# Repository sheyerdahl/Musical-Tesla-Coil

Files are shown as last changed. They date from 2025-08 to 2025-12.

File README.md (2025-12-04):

Welcome
======
A DRSSTC (Dual Resonant Solid State Tesla Coil) project that uses the ESP32-S3-WROOM-1 module as the microcontroller and wireless communication. 

My primary circuit uses the SKM100GB125DN IGBT

Notes
-------
The first revision (REV 1.0) being my first PCB, had quite a few issues and oversights. REV 2.0 will fix these issues, although it will be untested.
Some of the issues that were fixed:

Lack of OCD Comparator
Lack of peak detector circuit for measuring current
Lack of ZCD Comparator
USB-C footprint being incorrect
Slow diodes being used in the GDT circuit
Lack of mounting holes
Using built-in ADC of ESP32, an external one would have significantly more ENOB. (Effective Number Of Bits)
No Reverse polarity protection, no over current protection.

Credits
-------
Most design decisions were made because of Mads Barnkob and his awesome [website](https://kaizerpowerelectronics.dk/tesla-coils/drsstc-design-guide/) and [Youtube videos](https://www.youtube.com/@KaizerPowerElectronicsDk).

Thanks to those who worked on the [UD3 Board](https://github.com/Netzpfuscher/UD3), some of their hardware design was copied to this one.

[JAVATC3D](https://www.classictesla.com/java/javatc3d/javatc3d.html)

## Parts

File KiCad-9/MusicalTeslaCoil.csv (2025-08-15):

Id | Designator | Footprint | Quantity | Designation | Supplier and ref
1 | C1,C4,C37,C19,C24,C28,C36,C29 | C_0805_2012Metric_Pad1.18x1.45mm_HandSolder | 8 | 0.1uF
2 | J14 | PinHeader_2x03_P2.54mm_Vertical | 1 | Conn_02x03_Odd_Even
3 | C21,C7,C13,C33,C32,C26 | C_0805_2012Metric_Pad1.18x1.45mm_HandSolder | 6 | 1nF
4 | R10,R12 | R_0805_2012Metric_Pad1.20x1.40mm_HandSolder | 2 | 3k 1%
5 | J3 | Molex_KK-254_AE-6410-02A_1x02_P2.54mm_Vertical | 1 | VBUS
6 | C42,C2,C38,C39,C23,C35 | C_0805_2012Metric_Pad1.18x1.45mm_HandSolder | 6 | 1uF
7 | R13,R14,R29,R26,R21,R24,R30,R17 | R_0805_2012Metric_Pad1.20x1.40mm_HandSolder | 8 | 1k
8 | U3 | DCK5_TEX | 1 | LMV321
9 | C6 | C_0805_2012Metric_Pad1.18x1.45mm_HandSolder | 1 | 10nF
10 | R6,R2,R1,R27,R28,R22,R23 | R_0805_2012Metric_Pad1.20x1.40mm_HandSolder | 7 | 10k
11 | R15,R16 | R_0805_2012Metric_Pad1.20x1.40mm_HandSolder | 2 | 50
12 | J4 | Molex_KK-254_AE-6410-02A_1x02_P2.54mm_Vertical | 1 | Primary Relay
13 | Q1,Q2 | QNMOS1G2S3D_TO-236AB_SOT23_NEX | 2 | PMV20ENR
14 | CR1,CR11,CR10,CR9,CR8,CR2 | CR_SOD-123FL_SME | 6 | 1N4007FL
15 | J9 | Molex_KK-254_AE-6410-02A_1x02_P2.54mm_Vertical | 1 | NTC Thermistor 1
16 | U2 | SOT-23-6W_PE-SOT23-6W-0512_NMD | 1 | R1240N001B-TR-FE
17 | L1 | IND_7045_TDK | 1 | SLF7045T-4R7M2R0-PF
18 | CR13 | M-FLAT_TOS | 1 | CMS06TE12L_Q_M
19 | CR12 | DIODE_MSP3V3 | 1 | MSS1P4-M3/89A
20 | CR6,CR5,CR4,CR3 | DO-214AA_VIS | 4 | ES2B-E3/52T
21 | SW1 | SO4_222A-M-V-B_CTS | 1 | USB Boot
22 | U1 | ESP32-S3-WROOM-1 | 1 | ESP32-S3-WROOM-1
23 | SW2 | SO4_222A-M-V-B_CTS | 1 | Reset
24 | C3 | C_0805_2012Metric_Pad1.18x1.45mm_HandSolder | 1 | 22uF
25 | J1 | USB_C-UJ20-C-H-C-MSMT-TR | 1 | USB_C-UJ20-C-H-C-MSMT-TR
26 | R35 | R_0805_2012Metric_Pad1.20x1.40mm_HandSolder | 1 | 6.3k 1%
27 | C41 | C_0805_2012Metric_Pad1.18x1.45mm_HandSolder | 1 | 470pF
28 | R34 | R_0805_2012Metric_Pad1.20x1.40mm_HandSolder | 1 | 51
29 | U10 | SOT95P285X140-5N | 1 | AP2112K-3.3TRG1
30 | C40,C5 | C_0805_2012Metric_Pad1.18x1.45mm_HandSolder | 2 | 10uF
31 | R36 | R_0805_2012Metric_Pad1.20x1.40mm_HandSolder | 1 | 1.2k 1%
32 | J2 | Molex_KK-254_AE-6410-02A_1x02_P2.54mm_Vertical | 1 | Power in
33 | U5,U7 | SOIC127P599X175-8N | 2 | UCC27423DR
34 | C16,C15,C14,C17 | C_0805_2012Metric_Pad1.18x1.45mm_HandSolder | 4 | 150pF
35 | R39,R38,R37,R20 | R_0805_2012Metric_Pad1.20x1.40mm_HandSolder | 4 | 3.3 0.5W
36 | J13 | PinHeader_1x06_P2.54mm_Vertical | 1 | Conn_01x06_Pin
37 | J12 | PinHeader_1x05_P2.54mm_Vertical | 1 | Conn_01x05_Pin
38 | J11 | PinHeader_1x10_P2.54mm_Vertical | 1 | Conn_01x10_Pin
39 | C31,C30,C27,C18,C20,C25 | C_0805_2012Metric_Pad1.18x1.45mm_HandSolder | 6 | 4.7uF
40 | FL1 | FL4_WCM7060_TTA | 1 | WCM 7060FASF-701-LM
41 | R3,R11 | R_0805_2012Metric_Pad1.20x1.40mm_HandSolder | 2 | 5.1k
42 | J5 | Molex_KK-254_AE-6410-02A_1x02_P2.54mm_Vertical | 1 | Soft Start Bypass Relay
43 | CR7 | CR_V3-E3&slash_52_VIS | 1 | SMBJ3V3-E3/52
44 | J8 | Molex_KK-254_AE-6410-02A_1x02_P2.54mm_Vertical | 1 | GDT2
45 | R33,R32 | R_0805_2012Metric_Pad1.20x1.40mm_HandSolder | 2 | 1k 1%
46 | R25,R31 | R_0805_2012Metric_Pad1.20x1.40mm_HandSolder | 2 | 15
47 | R19,R18 | R_0805_2012Metric_Pad1.20x1.40mm_HandSolder | 2 | 100
48 | J7 | Molex_KK-254_AE-6410-02A_1x02_P2.54mm_Vertical | 1 | GDT1
49 | U4,U6,U9,U8 | TO252-4_DMC4029SK4-13_DIO | 4 | DMC4029SK4-13
50 | J6 | Molex_KK-254_AE-6410-02A_1x02_P2.54mm_Vertical | 1 | Current Transformer
51 | C22,C34 | C_0805_2012Metric_Pad1.18x1.45mm_HandSolder | 2 | 2.2uF
52 | J10 | Molex_KK-254_AE-6410-02A_1x02_P2.54mm_Vertical | 1 | NTC Thermistor 2
53 | R7 | R_0805_2012Metric_Pad1.20x1.40mm_HandSolder | 1 | 100k

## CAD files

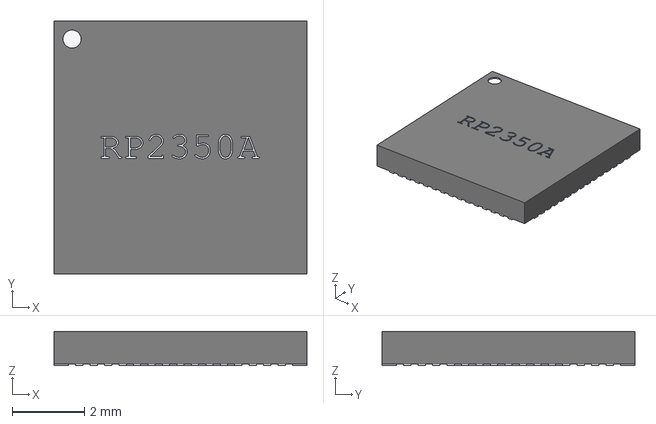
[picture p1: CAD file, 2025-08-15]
KiCad-9/MusicalTeslaCoil.step
7.00 x 7.00 x 0.95 mm

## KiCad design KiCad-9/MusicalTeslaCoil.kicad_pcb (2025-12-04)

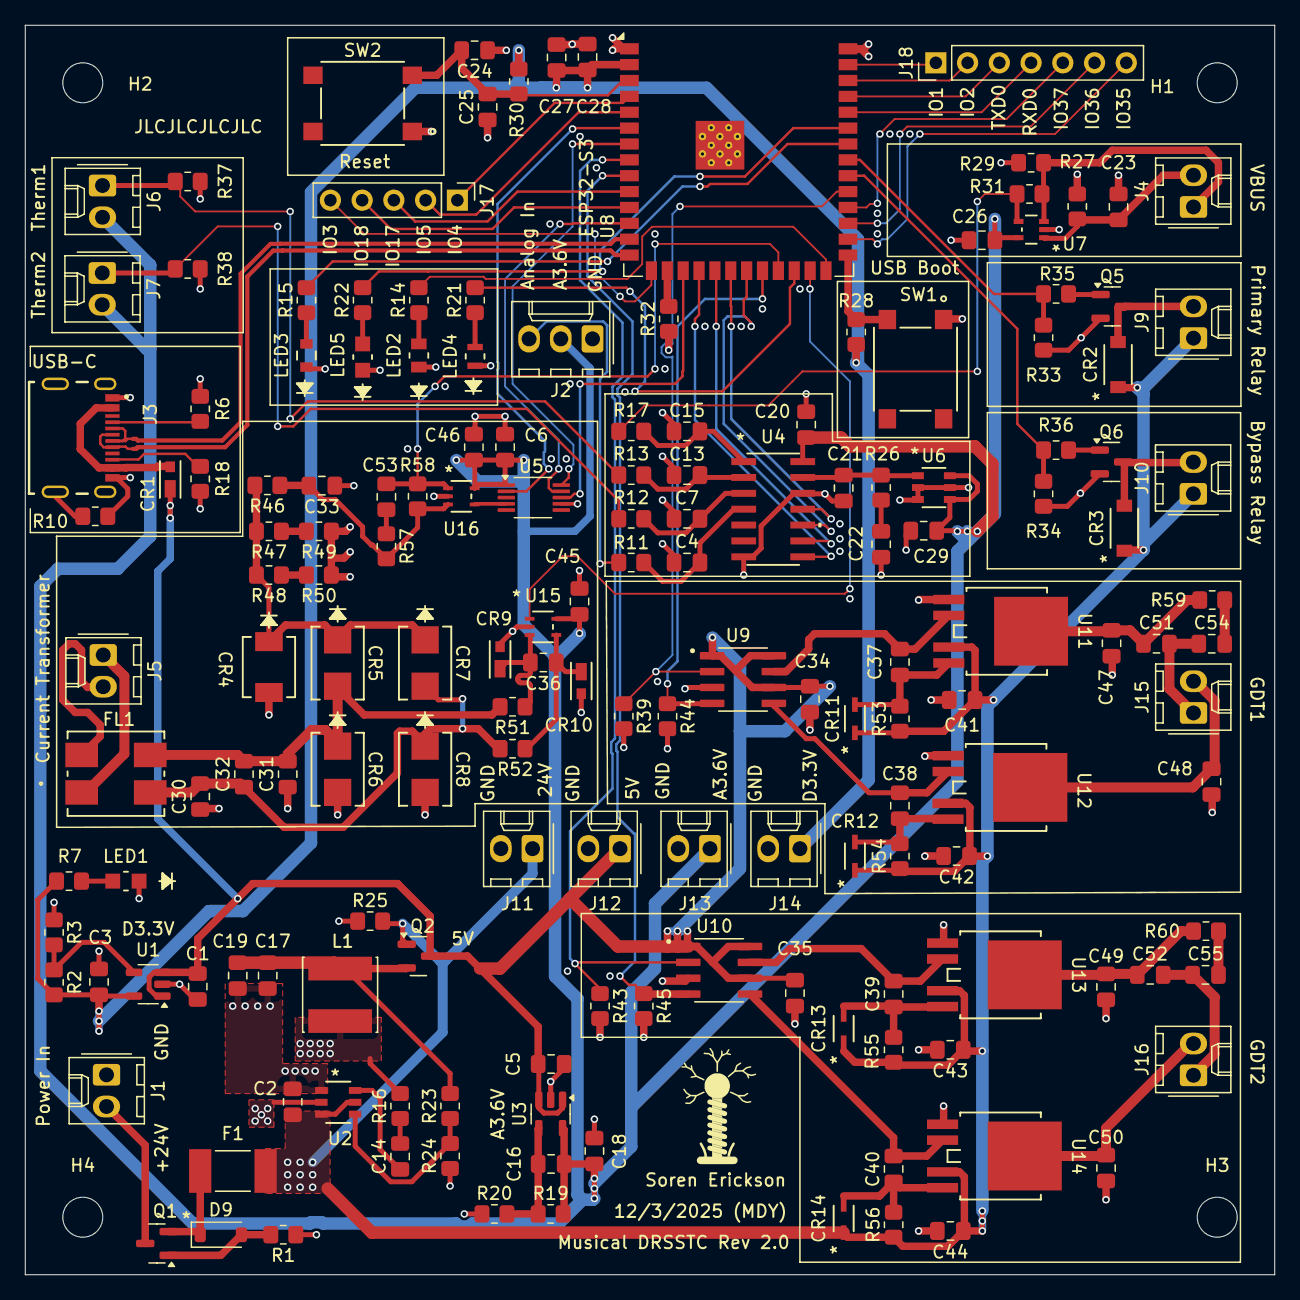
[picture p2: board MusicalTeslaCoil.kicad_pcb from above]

Board: 4 copper layers, 100.0 x 100.0 mm, 169 parts (0 on the bottom side), 105 nets.

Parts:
C1, C3, C5, C18, C20, C22, C29, C51, C52: 2.2uF; C_0805_2012Metric_Pad1.18x1.45mm_HandSolder
C2, C17, C19, C27, C28: 10uF; C_0805_2012Metric_Pad1.18x1.45mm_HandSolder
C4, C7, C13, C15, C16, C23: 10nF; C_0805_2012Metric_Pad1.18x1.45mm_HandSolder
C6, C25, C45, C46, C54, C55: 1uF; C_0805_2012Metric_Pad1.18x1.45mm_HandSolder
C14, C24, C26, C37, C38, C39, C40: 0.1uF; C_0805_2012Metric_Pad1.18x1.45mm_HandSolder
C21, C32, C47, C48, C49, C50: 1nF; C_0805_2012Metric_Pad1.18x1.45mm_HandSolder
C30, C31, C33, C36: 150pF; C_0805_2012Metric_Pad1.18x1.45mm_HandSolder
C34, C35, C41, C42, C43, C44: 4.7uF; C_0805_2012Metric_Pad1.18x1.45mm_HandSolder
C53: 470pF; C_0805_2012Metric_Pad1.18x1.45mm_HandSolder
CR1, CR9, CR10: MSS1P4-M3/89A; DIODE_MSP3V3
CR2, CR3: 1N4007FL; CR_SOD-123FL_SME
CR4: SMBJ3V3-E3/52; CR_V3-E3&slash_52_VIS
CR5, CR6, CR7, CR8: ES2B-E3/52T; DO-214AA_VIS
CR11, CR12, CR13, CR14: 1N4148WS-7-F; CR_SOD323_MCC
D9: BZT52C15-7-F; D_SOD-123
F1: 0ZCG0050AF2C; FUSER_0ZCG0050AF2C
FL1: WCM 7060FASF-701-LM; FL4_WCM7060_TTA
H1, H2, H3, H4: MountingHole; MountingHole_3.2mm_M3
J1: Power in; Molex_KK-254_AE-6410-02A_1x02_P2.54mm_Vertical
J2: Conn_01x03; Molex_KK-254_AE-6410-03A_1x03_P2.54mm_Vertical
J3: USB4215-03-A; USB4215_03_A
J4: VBUS; Molex_KK-254_AE-6410-02A_1x02_P2.54mm_Vertical
J5: Current Transformer; Molex_KK-254_AE-6410-02A_1x02_P2.54mm_Vertical
J6: NTC Thermistor 1; Molex_KK-254_AE-6410-02A_1x02_P2.54mm_Vertical
J7: NTC Thermistor 2; Molex_KK-254_AE-6410-02A_1x02_P2.54mm_Vertical
J9: Primary Relay; Molex_KK-254_AE-6410-02A_1x02_P2.54mm_Vertical
J10: Soft Start Bypass Relay; Molex_KK-254_AE-6410-02A_1x02_P2.54mm_Vertical
J11, J12, J13, J14: Conn_01x02; Molex_KK-254_AE-6410-02A_1x02_P2.54mm_Vertical
J15: GDT1; Molex_KK-254_AE-6410-02A_1x02_P2.54mm_Vertical
J16: GDT2; Molex_KK-254_AE-6410-02A_1x02_P2.54mm_Vertical
J17: Conn_01x05; PinHeader_1x05_P2.54mm_Vertical
J18: Conn_01x07; PinHeader_1x07_P2.54mm_Vertical
L1: VLS6045EX-150M; VLS6045EX_150M
LED1, LED5: LTST-C170GKT; LED_LTST-C170GKT_LTO
LED2: LTST-C170KFKT; LED_LTST-C170KFKT_LTO
LED3: LTST-C171KRKT; LED_LTST-C171_LTO
LED4: LTST-C170KSKT; LED_LTST-C170KSKT_LTO
Q1: GSF3407; SOT-23
Q2: SSF7912; SOT-23
Q5, Q6: 2N7002K; SOT-23
R1, R6, R18: 5.1k; R_0805_2012Metric_Pad1.20x1.40mm_HandSolder
R2, R19, R24, R29, R31: 3k; R_0805_2012Metric_Pad1.20x1.40mm_HandSolder
R3: 15k; R_0805_2012Metric_Pad1.20x1.40mm_HandSolder
R7, R14, R15, R21, R22, R57: 150; R_0805_2012Metric_Pad1.20x1.40mm_HandSolder
R10: 100k; R_0805_2012Metric_Pad1.20x1.40mm_HandSolder
R11, R12, R13, R17, R37, R38, R46, R51, R52, R53, R54, R55, R56: 1k; R_0805_2012Metric_Pad1.20x1.40mm_HandSolder
R16: 0; R_0805_2012Metric_Pad1.20x1.40mm_HandSolder
R20: 16.5k; R_0805_2012Metric_Pad1.20x1.40mm_HandSolder
R23: 22k; R_0805_2012Metric_Pad1.20x1.40mm_HandSolder
R25, R28, R30, R32, R33, R34, R39, R43, R44, R45: 10k; R_0805_2012Metric_Pad1.20x1.40mm_HandSolder
R26, R35, R36: 51; R_0805_2012Metric_Pad1.20x1.40mm_HandSolder
R27: 1.5k; R_0805_2012Metric_Pad1.20x1.40mm_HandSolder
R47, R48, R49, R50: 3.3 0.5W; R_0805_2012Metric_Pad1.20x1.40mm_HandSolder
R58: 200k; R_0805_2012Metric_Pad1.20x1.40mm_HandSolder
R59, R60: 15; R_0805_2012Metric_Pad1.20x1.40mm_HandSolder
SW1: USB Boot; SO4_222A-M-V-B_CTS
SW2: Reset; SO4_222A-M-V-B_CTS
U1, U3: TLV75801PDBV; SOT-23-5
U2: TPP362082-T6TR; TSOT23-6-A_TPK
U4: MCP3204T-CI/SL; SOIC14-N_MC_MCH
U5: MCP48FVB11
U6: MCP1501T-33E/CHY; SOT-23-6_CHY_MCH
U7: MCP6006UT-E/LT; SC70-5_LT_MCH
U8: ESP32-S3-WROOM-1
U9, U10: UCC27423DR; SOIC127P599X175-8N
U11, U12, U13, U14: DMC4029SK4-13; TO252-4_DMC4029SK4-13_DIO
U15, U16: NCS2250SQ2T2G; SC70-5_2P2X1P35_ONS

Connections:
5V: C1.2, C5.2, C34.2, C35.2, CR1.1, J12.1, Q2.3 (D), U1.1 (IN), U1.3 (EN), U3.1 (IN), U3.3 (EN), U9.1 (ENBA), U9.6 (VDD), U9.8 (ENBB), U10.1 (ENBA), U10.6 (VDD), U10.8 (ENBB)
24V: C2.1, C41.1, C42.1, C43.1, C44.1, CR2.1, CR3.1, CR11.1, CR12.1, CR13.1, CR14.1, F1.1, J9.1, J10.1, J11.1, Q2.1 (G), R25.2, R53.1, R54.1, R55.1, R56.1, U2.3 (VIN), U2.5 (EN), U11.3 (P-Chan_S), U12.3 (P-Chan_S), U13.3 (P-Chan_S), U14.3 (P-Chan_S)
A3.6V: C6.2, C16.2, C18.2, C20.2, C26.2, C29.2, C45.2, C46.2, J2.2, J6.2, J7.2, J13.1, R19.2, U3.5 (OUT), U4.14 (VDD), U5.1 (VDD), U6.4 (*SHDN), U6.6 (VDD), U7.5 (V+), U15.5 (V+), U16.5 (V+)
ADC_CLK: U4.11 (CLK), U8.20 (IO12)
ADC_CS: U4.8 (*CS/SHDN), U8.18 (IO10)
ADC_DIN: U4.9 (DIN), U8.19 (IO11)
ADC_DOUT: U4.10 (DOUT), U8.21 (IO13)
BypassRelay: R34.1, R36.2, U8.32 (IO39)
CTOut: C33.2, R46.1, R57.2, R58.2, U16.3 (+)
D3.3V: C3.2, C27.2, C28.1, J14.1, R2.2, R7.2, R28.1, R30.1, U1.5 (OUT), U8.2 (3V3)
DACVOut: U5.4 (VOut), U16.4 (-)
DAC_CLK: U5.9 (SCK), U8.12 (IO8)
DAC_CS: U5.2 (*CS), U8.6 (IO6)
DAC_DIN: U5.10 (SDI), U8.7 (IO7)
DAC_DOUT: U5.8 (SDO), U8.17 (IO9)
GD1-A: R39.1, U8.31 (IO38), U9.2 (INA)
GD1-B: R44.1, U8.22 (IO14), U9.4 (INB)
GD2-A: R43.1, U8.8 (IO15), U10.2 (INA)
GD2-B: R45.1, U8.9 (IO16), U10.4 (INB)
GND: C1.1, C2.2, C3.1, C4.1, C5.1, C6.1, C7.1, C13.1, C15.1, C17.2, C18.1, C19.2, C20.1, C21.1, C22.1, C23.1, C24.1, C25.1, C26.1, C27.1, C28.2, C29.1, C30.1, C31.1, C33.1, C34.1, C35.1, C41.2, C42.2, C43.2, C44.2, C45.1, C46.1, C47.2, C48.2, C49.2, C50.2, CR4.2, CR6.2, CR8.2, CR9.2, CR10.2, J1.1, J2.1, J3.A1_B12 (GND_A), J3.B1_A12 (GND_B), J11.2, J12.2, J13.2, J14.2, LED1.1, LED2.1, LED3.1, LED4.1, LED5.1, Q5.2 (S), Q6.2 (S), R1.1, R3.1, R6.1, R10.2, R18.1, R20.1, R24.1, R25.1, R27.1, R29.1, R32.1, R33.2, R34.2, R37.2, R38.2, R39.2, R43.2, R44.2, R45.2, R49.1, R50.1, SW1.1 (A), SW2.1 (A), U1.2 (GND), U2.1 (GND), U3.2 (GND), U4.7 (DGND), U4.12 (AGND), U5.7 (GND), U6.2 (GND), U6.3 (GND), U6.5 (GND), U7.2 (V-), U8.1 (GND), U8.40 (GND), U8.41 (GND), U9.3 (GND), U10.3 (GND), U11.1 (N-Chan_S), U12.1 (N-Chan_S), U13.1 (N-Chan_S), U14.1 (N-Chan_S), U15.2 (V-), U16.2 (V-)
IO1: J18.1, U8.39 (IO1)
IO2: J18.2, U8.38 (IO2)
IO3: J17.5, U8.15 (IO3)
IO4: J17.1, U8.4 (IO4)
IO5: J17.2, U8.5 (IO5)
IO17: J17.3, U8.10 (IO17)
IO18: J17.4, U8.11 (IO18)
IO35: J18.7, U8.28 (IO35)
IO36: J18.6, U8.29 (IO36)
IO37: J18.5, U8.30 (IO37)
LED1: R15.2, U8.34 (IO41)
LED2: R22.2, U8.35 (IO42)
LED3: R14.2, U8.26 (IO45)
LED4: R21.2, U8.24 (IO47)
unnamed: C14.2, R16.1
unnamed: C22.2, R26.1
unnamed: C30.2, C32.1, CR7.2, CR8.1, FL1.3, R52.2
unnamed: C31.2, C32.2, CR5.2, CR6.1, FL1.4, R51.2
unnamed: C53.2, R57.1
unnamed: C54.2, R59.2
unnamed: C55.2, R60.2
unnamed: CR4.1, CR5.1, CR7.1, R46.2, R47.2, R48.2
unnamed: D9.2 (A), Q1.1 (G), R1.2
unnamed: D9.1 (K), F1.2, Q1.2 (S)
unnamed: J1.2, Q1.3 (D)
unnamed: J2.3, R11.2
unnamed: J3.A5 (CC1), R6.2
unnamed: J3.B5 (CC2), R18.2
unnamed: J3.SH4 (SHIELD__3), R10.1
unnamed: CR1.2, J3.A4_B9 (VBUS_A), J3.B4_A9 (VBUS_B)
unnamed: J4.1, R29.2, R31.2, U7.3 (-)
unnamed: C23.2, J4.2, R27.2, U7.1 (+)
unnamed: FL1.2, J5.1
unnamed: FL1.1, J5.2
unnamed: CR2.2, J9.2, Q5.3 (D)
unnamed: CR3.2, J10.2, Q6.3 (D)
unnamed: C51.1, C54.1, J15.1
unnamed: C48.1, J15.2, U12.5 (Drain)
unnamed: C52.1, C55.1, J16.1
unnamed: C50.1, J16.2, U14.5 (Drain)
unnamed: LED1.2, R7.1
unnamed: LED2.2, R14.1
unnamed: LED3.2, R15.1
unnamed: LED4.2, R21.1
unnamed: LED5.2, R22.1
unnamed: C17.1, C19.1, L1.2, Q2.2 (S), R23.2
unnamed: Q5.1 (G), R35.1
unnamed: Q6.1 (G), R36.1
unnamed: R47.1, R49.2
unnamed: R48.1, R50.2
unnamed: R28.2, SW1.2 (B), U8.27 (IO0)
unnamed: C24.2, C25.2, R30.2, SW2.2 (B), U8.3 (EN)
unnamed: R2.1, R3.2, U1.4 (FB)
unnamed: L1.1, R16.2, U2.2 (SW)
unnamed: C14.1, U2.6 (VBST)
unnamed: R23.1, R24.2, U2.4 (VFB)
unnamed: C16.1, R19.1, R20.2, U3.4 (FB)
unnamed: C15.2, R17.1, U4.1 (CH0)
unnamed: C13.2, R13.1, U4.2 (CH1)
unnamed: C7.2, R12.1, U4.3 (CH2)
unnamed: C4.2, R11.1, U4.4 (CH3)
unnamed: C21.2, R26.2, U4.13 (VREF), U6.1 (OUT)
unnamed: R32.2, U8.16 (IO46)
unnamed: C39.2, U10.7 (OUTA), U13.2 (N-Chan_G)
unnamed: C40.2, U10.5 (OUTB), U14.2 (N-Chan_G)
unnamed: C47.1, C51.2, R59.1, U11.5 (Drain)
unnamed: C37.2, U9.7 (OUTA), U11.2 (N-Chan_G)
unnamed: C37.1, CR11.2, R53.2, U11.4 (P-Chan_G)
unnamed: C38.2, U9.5 (OUTB), U12.2 (N-Chan_G)
unnamed: C38.1, CR12.2, R54.2, U12.4 (P-Chan_G)
unnamed: C49.1, C52.2, R60.1, U13.5 (Drain)
unnamed: C39.1, CR13.2, R55.2, U13.4 (P-Chan_G)
unnamed: C40.1, CR14.2, R56.2, U14.4 (P-Chan_G)
unnamed: C36.2, CR9.1, R51.1, U15.3 (+)
unnamed: C36.1, CR10.1, R52.1, U15.4 (-)
OCDInterrupt: C53.1, R58.1, U8.23 (IO21), U16.1
PrimaryRelay: R33.1, R35.2, U8.33 (IO40)
RXD0: J18.4, U8.36 (RXD0)
TXD0: J18.3, U8.37 (TXD0)
Therm1: J6.1, R13.2, R37.1
Therm2: J7.1, R12.2, R38.1
USB_D+: J3.A6 (DP1), J3.B6 (DP2), U8.14 (USB_D+)
USB_D-: J3.A7 (DN1), J3.B7 (DN2), U8.13 (USB_D-)
VBUS: R17.2, R31.1, U7.4
ZCDInterrupt: U8.25 (IO48), U15.1

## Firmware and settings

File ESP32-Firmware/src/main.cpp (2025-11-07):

// Inclues
#include <Arduino.h>
//#include "WifiOta.h"
#include "BleControl.h"
#include "MidiControl.h"
#include "ZCD.h"
#include "FastAnalogRead.h"
#include "CurrentTransformer.h"
#include "GateDrive.h"
#include "FrequencySweep.h"
#include "Relay.h"
#include "Burst.h"
#include "VBus.h"
#include "OCD.h"

// Constants
const uint16_t startFrequency = 400; // In KHz
const uint16_t maxBurstLength = 200; // In uS
const uint16_t externalResistanceKiloOhms = 400;
const uint16_t ocdCurrent = 400;
const uint16_t ctTurnsRatio = 512;
const uint32_t ctBurdenMiliohms = 3300;

// Pins
// const uint8_t CurrentTransformerPin = 2;
// const uint8_t ZCDAPin = 3;
// const uint8_t ZCDBPin = 4;
const uint8_t Therm1Pin = 5;
const uint8_t Therm2Pin = 6;
const uint8_t PrimaryRelayPin = 11;
const uint8_t BypassRelayPin = 12;
const uint8_t GD1APin = 13;
const uint8_t GD1BPin = 14;
const uint8_t GD2APin = 15;
const uint8_t GD2BPin = 16;
const uint8_t ZCDInterruptPin = 21;
const uint8_t CTPeakResetPin = 45;

// Analog Pins
const uint8_t CTPeakPin = 9;
const uint8_t VbusPin = 1;

// Variables
float test = 0.0f;
unsigned long lastMicros = 0;

uint32_t adcSamples = 0;

TaskHandle_t Task0;

// Functions
void setup() {
	Serial.begin(115200);
	// while (!Serial) {
	// 	delay(100);
	// }
	Serial.println("Starting up...");

	// Initialize the FastADC library
    fadcInit(2, CTPeakPin, VbusPin);
	//WifiOta::begin(WIFI_SSID, WIFI_PASSWORD, "tesla-coil");

	GateDrive::begin(GD1APin, GD1BPin, GD2APin, GD2BPin);
	BleControl::begin("TeslaCoil");
	MidiControl::begin();
	ZCD::begin(ZCDInterruptPin, GD1APin, GD1BPin);
	CurrentTransformer::begin(CTPeakPin, CTPeakResetPin);
	FrequencySweep::begin(GD1APin, GD1BPin);
	Relay::begin(PrimaryRelayPin, BypassRelayPin);
	VBus::begin(VbusPin, externalResistanceKiloOhms);
	OCD::begin(ocdCurrent, ctTurnsRatio, ctBurdenMiliohms);
}

void loop() {
  	//WifiOta::handle();
	FrequencySweep::handle();
	Burst::handle();

	BleControl::ControlState controlState = BleControl::getState();
	(void)controlState;
	// Read sensors (placeholder analogReads; adjust scaling as needed)
	// float vbus = analogRead(VbusPin);
	//float ct = CurrentTransformer::readCurrentTransformer();
	// float t1 = analogRead(Therm1Pin);
	// float t2 = analogRead(Therm2Pin);
	//float cpuFrequency = getCpuFrequencyMhz();
	uint16_t vBusVoltage = VBus::readVBus();
	BleControl::notifyReadings(vBusVoltage, test, 0, 0);
	Relay::setEnabled(controlState.enabled);
	// Serial.print("Enabled: ");
	// Serial.print(s.enabled);
	// Serial.print(", Burst Length: ");
	// Serial.print(s.burstLength);
	// Serial.print(", BPS: ");
	// Serial.print(s.bps);
	// Serial.println();

	test += float(micros() - lastMicros) * 0.000001f;
	lastMicros = micros();
	if (test > 4.0f) {
		// Serial.print("Test reset, core is: ");
		// Serial.println(xPortGetCoreID());
		test = 0.0f;
		size_t freeHeap = ESP.getFreeHeap();
		//size_t largestFreeBlock = ESP.getMaxAllocHeap();
		size_t freePsram = ESP.getFreePsram();
		//size_t largestFreeBlockPsram = ESP.getMaxAllocPsram();
		Serial.print("Free heap: ");
		Serial.print(freeHeap);
		Serial.print(", Free PSRAM: ");
		Serial.print(freePsram);
		Serial.println(" bytes");
	}
	delay(100);
	//delayMicroseconds(1);
}

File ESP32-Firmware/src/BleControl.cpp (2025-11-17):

#include "BleControl.h"
#include "MidiControl.h"

#include <BLEDevice.h>
#include <BLEUtils.h>
#include <BLEServer.h>
#include <BLE2902.h>

namespace {
	BLE2902* pid2902 = new BLE2902();
	// UUIDs (randomly generated).
	const char* SERVICE_UUID =  "08160660-e062-460c-8834-06f539975761"; // insert uuid here
	const char* UUID_VBUS =     "18160660-e062-460c-8834-06f539975761"; // float notify
	const char* UUID_CT =       "28160660-e062-460c-8834-06f539975761"; // float notify
	const char* UUID_THERM1 =   "38160660-e062-460c-8834-06f539975761"; // float notify
	const char* UUID_THERM2 =   "48160660-e062-460c-8834-06f539975761"; // float notify
	const char* UUID_TOGGLE =   "58160660-e062-460c-8834-06f539975761"; // bool write
	const char* UUID_BURST = "68160660-e062-460c-8834-06f539975761"; // u16 write
	const char* UUID_BPS =      "78160660-e062-460c-8834-06f539975761"; // u16 write
	const char* UUID_BURST_ENABLED = "88160660-e062-460c-8834-06f539975761"; // bool write
	const char* UUID_PHASE_LEAD = "98160660-e062-460c-8834-06f539975761"; // u16 write
	const char* UUID_REVERSE_BURST_PHASE = "a8160660-e062-460c-8834-06f539975761"; // bool write
	const char *MIDI_UPLOAD = "b8160660-e062-460c-8834-06f539975761"; // chunked write
	const char *PLAY_MIDI = "c8160660-e062-460c-8834-06f539975761"; // bool write
	const char *UUID_MIDI_OCTAVE = "d8160660-e062-460c-8834-06f539975761"; // int8 write
	const char *UUID_CHORD_SWAP_TIME = "e8160660-e062-460c-8834-06f539975761"; // uint8 write

	const char* FREQUENCY_SWEEP_SERVICE_UUID =  "08160661-e062-460c-8834-06f539975761"; // insert uuid here
	const char* UUID_MIN_FREQ_SWEEP = "08160662-e062-460c-8834-06f539975761"; // u16 write
	const char* UUID_MAX_FREQ_SWEEP = "08160663-e062-460c-8834-06f539975761"; // u16 write
	const char* UUID_START_FREQ_SWEEP = "08160664-e062-460c-8834-06f539975761"; // bool write
	const char* UUID_FREQ_SWEEP_DATA = "08160665-e062-460c-8834-06f539975761"; // u32 read

	const BLEUUID* serviceBLEUUID = new BLEUUID(SERVICE_UUID);

	BLEServer* server = nullptr;
	BLEService* service = nullptr;
	BLEService* frequencySweepService = nullptr;
	BLECharacteristic* chVbus = nullptr;
	BLECharacteristic* chCt = nullptr;
	BLECharacteristic* chTherm1 = nullptr;
	BLECharacteristic* chTherm2 = nullptr;
	BLECharacteristic* chToggle = nullptr;
	BLECharacteristic* chBurst = nullptr;
	BLECharacteristic* chBps = nullptr;
	BLECharacteristic* chBurstEnabled = nullptr;
	BLECharacteristic* chPhaseLead = nullptr;
	BLECharacteristic* chReverseBurstPhase = nullptr;
	BLECharacteristic* chMinFreqSweep = nullptr;
	BLECharacteristic* chMaxFreqSweep = nullptr;
	BLECharacteristic* chStartFreqSweep = nullptr;
	BLECharacteristic* chFreqSweepData = nullptr;
	BLECharacteristic* chMidiUpload = nullptr;
	BLECharacteristic* chPlayMidi = nullptr;
	BLECharacteristic* chMidiOctave = nullptr;
	BLECharacteristic* chChordSwapTime = nullptr;

	BleControl::ControlState state { false, 100, 2, 90, 110, false, false, 0, false, 0, 20 };

	class ControlCallbacks : public BLECharacteristicCallbacks {
		void onWrite(BLECharacteristic* characteristic) override {
			std::string value = characteristic->getValue();
			// Serial.println("Characteristic was written to:");
			// Serial.println(characteristic == chStartFreqSweep);
			// Serial.println(value.size());
			if (characteristic == chToggle) {
				state.enabled = (!value.empty() && value[0] != 0);
			} else if (characteristic == chBurst) {
				if (value.size() >= 2) {
					uint16_t v = ((uint8_t)value[0]) | (((uint8_t)value[1]) << 8);
					state.burstLength = v;
				}
			} else if (characteristic == chBps) {
				if (value.size() >= 2) {
					uint16_t v = ((uint8_t)value[0]) | (((uint8_t)value[1]) << 8);
					state.bps = v;
				}
			} else if (characteristic == chMinFreqSweep) {
				if (value.size() >= 2) {
					uint16_t v = ((uint8_t)value[0]) | (((uint8_t)value[1]) << 8);
					state.minFrequencySweep = v;
				}
			} else if (characteristic == chMaxFreqSweep) {
				if (value.size() >= 2) {
					uint16_t v = ((uint8_t)value[0]) | (((uint8_t)value[1]) << 8);
					state.maxFrequencySweep = v;
				}
			} else if (characteristic == chStartFreqSweep) {
				state.startFrequencySweep = (!value.empty() && (uint8_t)value[0] != 0);
			} else if (characteristic == chBurstEnabled) {
				state.burstEnabled = (!value.empty() && (uint8_t)value[0] != 0);
			} else if (characteristic == chPhaseLead) {
				if (value.size() >= 2) {
					uint16_t v = ((uint8_t)value[0]) | (((uint8_t)value[1]) << 8);
					state.phaseLead = v;
				}
			} else if (characteristic == chReverseBurstPhase) {
				state.reverseBurstPhase = (!value.empty() && (uint8_t)value[0] != 0);
			} else if (characteristic == chMidiUpload) {
				// Forward chunk to MidiControl
				Serial.println("MidiUpload");
				Serial.print(value.size());
				Serial.print(" | ");
				Serial.println(value.data());
				if (!value.empty()) {
					MidiControl::receiveChunk((const uint8_t*)value.data(), value.size());
				} else {
					// Empty chunk signals end of transfer
					MidiControl::receiveChunk(nullptr, 0);
				}
			} else if (characteristic == chPlayMidi) {
				bool playMidi = (!value.empty() && (uint8_t)value[0] != 0);
				MidiControl::setPlaying(playMidi);
			} else if (characteristic == chMidiOctave) {
				if (!value.empty()) {
					int8_t octave = (int8_t)value[0];
					state.midiOctave = octave;
				}
			} else if (characteristic == chChordSwapTime) {
				if (!value.empty()) {
					uint8_t chordSwapTime = (uint8_t)value[0];
					state.chordSwapTime = chordSwapTime;
				}
			}
		}
	};

	class ServerCallbacks : public BLEServerCallbacks {
		void onConnect(BLEServer* pServer) override {
			// Client connected
		}

		void onDisconnect(BLEServer* pServer) override {
			// Disable burstEnabled when client disconnects
			state.burstEnabled = false;
			
			// Start advertising again to reconnect with the client
			BLEDevice::startAdvertising();
		}
	};
}
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

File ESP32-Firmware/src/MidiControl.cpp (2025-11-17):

#include "MidiControl.h"
#include "BleControl.h"
#include <sstream>
#include "MidiFile.h"

// Constants
//Note frequency lookup table
const uint32_t Midi_NoteFreq_dHz[] = {82, 87, 92, 97, 103, 109, 116, 122, 130, 138, 146, 154, 164, 173, 184, 194, 206, 218, 231, 245, 260, 275, 291, 309, 327, 346, 367, 389, 412, 437, 462, 490, 519, 550, 583, 617, 654, 693, 734, 778, 824, 873, 925, 980, 1038, 1100, 1165, 1235, 1308, 1386, 1468, 1556, 1648, 1746, 1850, 1960, 2077, 2200, 2331, 2469, 2616, 2772, 2937, 3111, 3296, 3492, 3700, 3920, 4153, 4400, 4662, 4939, 5233, 5544, 5873, 6223, 6593, 6985, 7400, 7840, 8306, 8800, 9323, 9878, 10465, 11087, 11747, 12445, 13185, 13969, 14800, 15680, 16612, 17600, 18647, 19755, 20930, 22175, 23493, 24890, 26370, 27938, 29600, 31360, 33224, 35200, 37293, 39511, 41860, 44349, 46986, 49780, 52740, 55877, 59199, 62719, 66449, 70400, 74586, 79021, 83720, 88698, 93973, 99561, 105481, 111753, 118398, 125439};

namespace MidiControl {
    std::vector<uint8_t> midiBuffer;
	bool fileReady = false;
	bool transferInProgress = false;
	
	// Playback state
	bool isPlaying = false;
	smf::MidiFile midiFile;
	bool midiFileLoaded = false;
	unsigned long playbackStartTime = 0;
	unsigned long chordSwitchTimestampMs = 0;
	size_t currentEventIndex = 0;
    TaskHandle_t playMidiTaskHandle;
	//std::vector<uint8_t> onNotes = {};
	uint8_t onNotes[5] = {0, 0, 0, 0, 0};
	uint8_t currentPlayingNote = 0;

	void begin() {
		midiBuffer.clear();
		fileReady = false;
		transferInProgress = false;
		playMidiTaskHandle = NULL;
	}
	
	bool receiveChunk(const uint8_t* data, size_t length) {
		if (data == nullptr || length == 0) {
			// Empty chunk signals end of transfer
			if (transferInProgress) {
				fileReady = true;
				transferInProgress = false;
				// Reset loaded state so new file will be loaded on next play
				// midiFileLoaded = false;
				// sortedEvents.clear();
				// isPlaying = false;
				return true;
			}
			return false;
		}
		
		// If starting a new transfer, clear old data
		if (!transferInProgress) {
			midiBuffer.clear();
			midiFileLoaded = false;
			//sortedEvents.clear();
			//isPlaying = false;
            setPlaying(false);
		}
		
		// Append chunk to buffer
		transferInProgress = true;
		midiBuffer.insert(midiBuffer.end(), data, data + length);
		
		// Transfer is still in progress, not complete yet
		return false;
	}
	
	bool isFileReady() {
		return fileReady;
	}
	
	const std::vector<uint8_t>& getMidiData() {
		return midiBuffer;
	}
	
	std::istringstream createInputStream() {
		// Create a string from the vector data
		std::string midiString(reinterpret_cast<const char*>(midiBuffer.data()), midiBuffer.size());
		std::istringstream stream(midiString);
		return stream;
	}
	
	void clear() {
		midiBuffer.clear();
		fileReady = false;
		transferInProgress = false;
		// Reset playback state
		//isPlaying = false;
        setPlaying(false);
		midiFileLoaded = false;
		//sortedEvents.clear();
		//midiFile.clear();
		currentEventIndex = 0;
	}
	
	size_t getBufferSize() {
		return midiBuffer.size();
	}
	
	void setPlaying(bool playing) {
		if (playing && !isPlaying) {
			// Start playback
			Serial.println("setPlaying true");
			if (!midiFileLoaded && isFileReady()) {
				Serial.println("Loading MidiFile");
				// Load MIDI file
				// Between HERE
				std::istringstream stream = createInputStream();
				if (midiFile.read(stream)) {
					Serial.println("MidiFile loaded");
					midiFileLoaded = true;
					midiFile.doTimeAnalysis();
					midiFile.linkNotePairs();
					//midiFile.joinTracks();
					
					currentEventIndex = 0;
					playbackStartTime = millis();
				}
			}
			
			if (midiFileLoaded) {
				isPlaying = true;
				currentEventIndex = 0;
				playbackStartTime = millis();
				// Make sure we don't have a dangling task handle
				if (playMidiTaskHandle != NULL) {
					vTaskDelete(playMidiTaskHandle);
					playMidiTaskHandle = NULL;
				}
				// and HERE is where the heap is being gobbled
				// Check available heap before creating task
				size_t freeHeap = ESP.getFreeHeap();
				//size_t largestFreeBlock = ESP.getMaxAllocHeap();
				size_t freePsram = ESP.getFreePsram();
				Serial.print("Free heap before task creation: ");
				Serial.print(freeHeap);
				Serial.print(", Free PSRAM: ");
				Serial.print(freePsram);
				Serial.println(" bytes");
				
				BaseType_t result = xTaskCreate(playMidiTask, "playMidiTask", 4096, NULL, 3, &playMidiTaskHandle);
				if (result == pdPASS) {
					Serial.print("playMidiTask created successfully with ");
				} else {
					Serial.print("Failed with stack size ");
					Serial.println(result);
				}
				
				Serial.print("Free heap AFTER task creation: ");
				Serial.print(freeHeap);
				Serial.print(", Free PSRAM: ");
				Serial.print(freePsram);
				Serial.println(" bytes");
			}
		} else if (!playing && isPlaying) {
			Serial.println("deleting playMidiTask...");
			// Stop playback
			isPlaying = false;
			if (playMidiTaskHandle != NULL) {
				vTaskDelete(playMidiTaskHandle);
				playMidiTaskHandle = NULL;
			}
			clearOnNotes();
			Serial.println("playMidiTask deleted");
		}
	}
	
	void addOnNote(uint8_t note) {
		for (uint8_t i = 0; i < 5; i++) {
			uint8_t onNote = onNotes[i];
			if (onNote == 0) {
				onNotes[i] = note;
				break;
			}
		}
	}

	void removeOnNote(uint8_t note) {
		for (uint8_t i = 0; i < 5; i++) {
			uint8_t onNote = onNotes[i];
			if (onNote == note) {
				onNotes[i] = 0;
				break;
			}
		}

		if (note == currentPlayingNote) {
			stopNote();
		}
	}

	void clearOnNotes() {
		stopNote();
		for (uint8_t i = 0; i < 5; i++) {
			onNotes[i] = 0;
		}
	}

	void playNote(uint8_t note) {
		BleControl::ControlState controlState = BleControl::getState();
		int8_t octave = controlState.midiOctave;
		uint32_t noteFreq = Midi_NoteFreq_dHz[note] / 10;

		if (octave > 0) {
			noteFreq *= 1 << octave;
		} else if (octave < 0) {
			noteFreq /= 1 << -octave;
		}

		BleControl::setBps(noteFreq);
		currentPlayingNote = note;
	}

	void stopNote() {
		currentPlayingNote = 0;
		BleControl::setBps(1);
	}

	int8_t getIndexOfOnNote(uint8_t note) {
		for (uint8_t i = 0; i < 5; i++) {
			uint8_t onNote = onNotes[i];
			if (onNote == note) {
				return i;
			}
		}

		return -1;
	}

	void playNextOnNote() {
		if (currentPlayingNote == 0) {
			return;
		}

		int8_t noteIndex = getIndexOfOnNote(currentPlayingNote);
		if (noteIndex == -1) {
			return;
		}

		bool noteFound = false;
		// Find first note after the current one
		for (uint8_t i = noteIndex + 1; i < 5; i++) {
			uint8_t onNote = onNotes[i];
			if (onNote != 0) {
				noteFound = true;
				playNote(onNote);
				break;
			}
		}

		// Loop back around if the previous loop didn't find a note.
		if (!noteFound) {
			for (uint8_t i = 0; i < noteIndex; i++) {
				uint8_t onNote = onNotes[i];
				if (onNote != 0) {
					playNote(onNote);
					break;
				}
			}
		}
	}
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

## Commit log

2025-08-15 Renamed MusicalTeslaCoil folder to KiCad-9
    [MusicalTeslaCoil.kicad_pcb]
2025-11-07 Added ESP32 firmware
2025-11-07 Fixed crash on midi song ending
    [MidiControl.cpp, main.cpp]
2025-11-12 Driver board can now reconnect BLE connection
2025-11-17 Added Chord Swap Time slider.
    [BleControl.cpp, MidiControl.cpp]
2025-12-04 Uploaded Rev 2.0
    [MusicalTeslaCoil-B_Cu.gbr, MusicalTeslaCoil-B_Mask.gbr, MusicalTeslaCoil-B_Paste.gbr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]
